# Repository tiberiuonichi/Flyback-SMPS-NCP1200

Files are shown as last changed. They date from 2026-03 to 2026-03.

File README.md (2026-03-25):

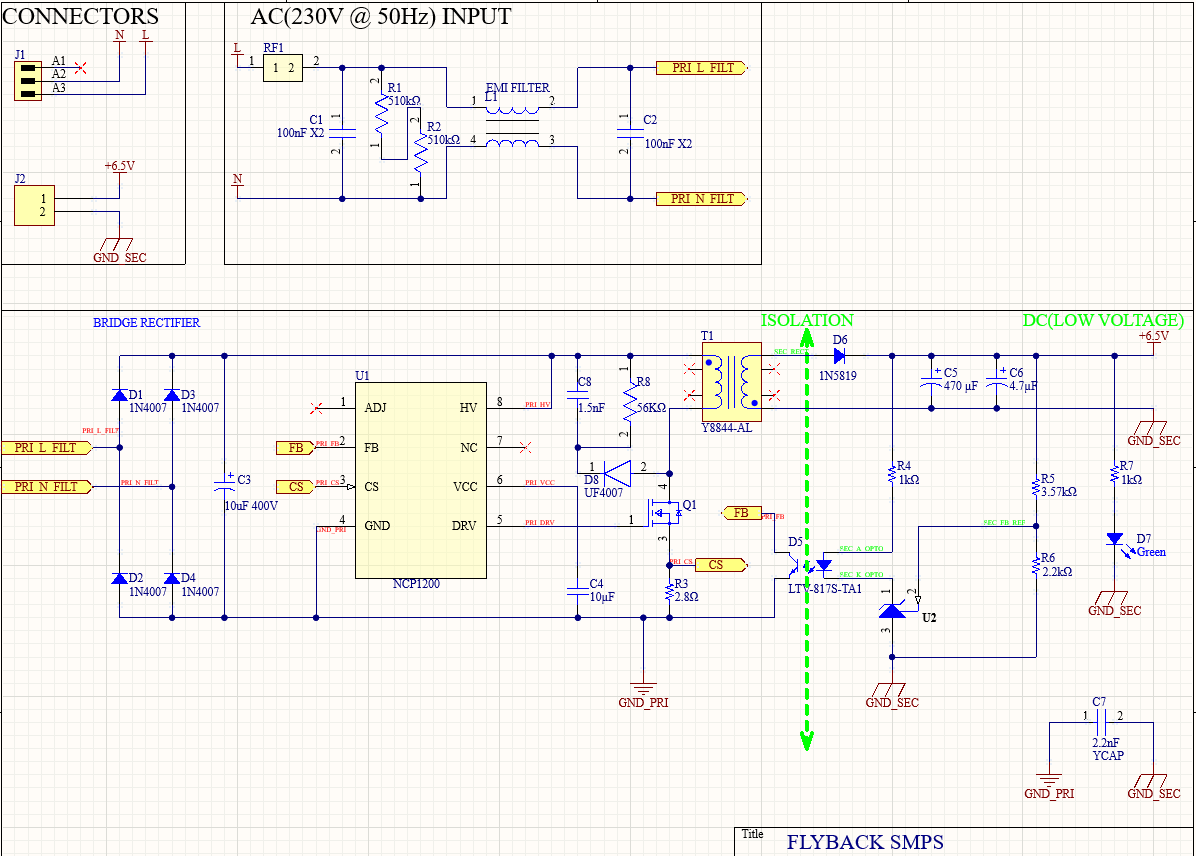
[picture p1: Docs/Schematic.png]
Schematic Preview

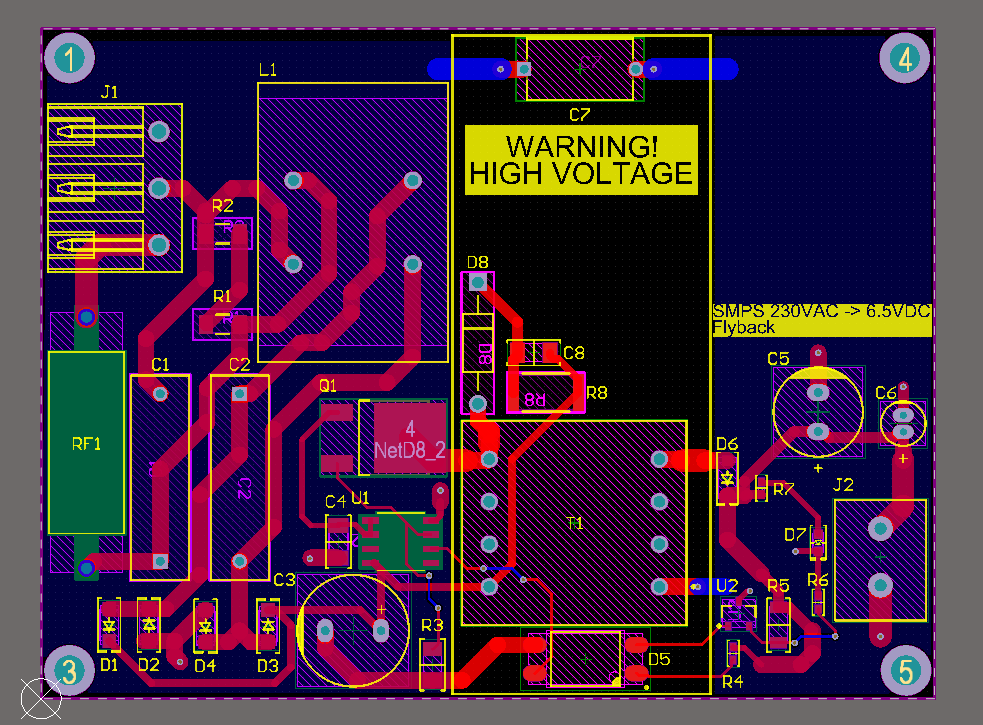
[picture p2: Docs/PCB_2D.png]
2D PCB Preview

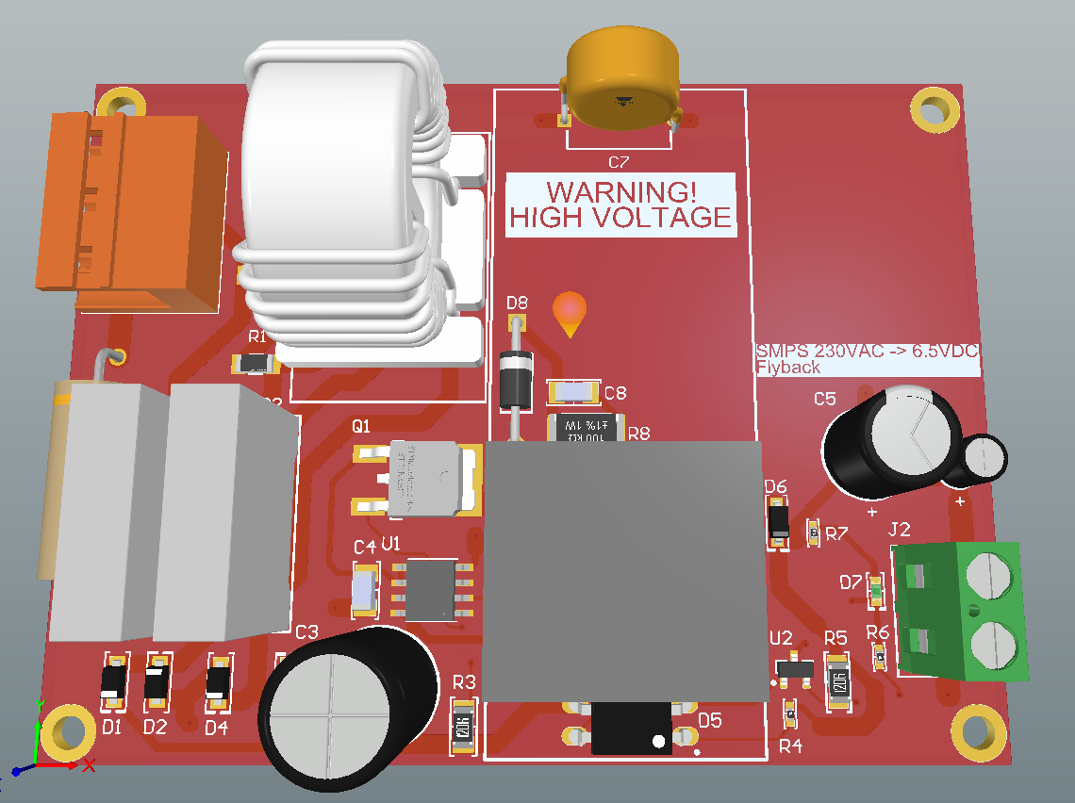
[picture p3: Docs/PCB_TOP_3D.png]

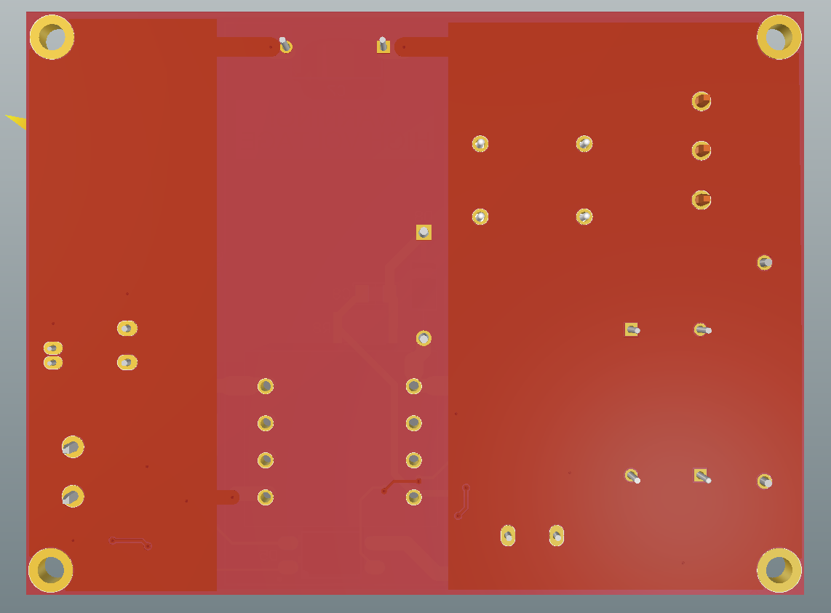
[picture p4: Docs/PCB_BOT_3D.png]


# 15W Isolated Flyback SMPS (230VAC to 6.5VDC)

## Project Overview
This repository contains the full hardware design for a compact, high-voltage Switch Mode Power Supply (SMPS). The design is based on the NCP1200 PWM controller and is optimized for low component count while maintaining high reliability and safety.

The project was developed using Altium Designer and includes everything from schematics and PCB layout to manufacturing files (Gerbers) and a detailed Bill of Materials (BOM).

## Technical Specifications
| Parameter | Value |
|---|---|
| Input Voltage | 230V AC @ 50Hz (Nominal) |
| Output Voltage | 6.5V DC (Regulated) |
| Max Power Output | ~15W |
| Topology | Isolated Flyback |
| Controller | ON Semi NCP1200 (Current-Mode PWM) |
| Switching Freq | 100 kHz |
| Feedback Loop | Optoisolated (LTV-817) with TL431 Shunt Regulator |

## Key Features and Design Decisions

### 1. Safety and Mechanical Design (Class I Isolation)
The input connector (J1) features a 3-pin configuration where Pin 3 is designated for Protective Earth (PE).
- Chassis Grounding: The design is intended to be housed in a metallic enclosure where PE is bonded to the chassis.
- Creepage and Clearance: PCB layout follows strict distance rules between Primary and Secondary sides to ensure galvanic isolation and user safety.

### 2. EMI Management
To comply with electromagnetic compatibility standards, the design includes:
- Input Pi-Filter: Common Mode Choke (L1) and X2 Capacitor (C1,C2) to reduce conducted emissions.
- Y-Capacitors (C7): Strategically placed to provide a low-impedance path for switching noise across the isolation barrier.

### 3. Efficiency and BOM Optimization
- NCP1200 Benefits: By using the NCP1200's internal high-voltage current source for startup, the design eliminates the need for an auxiliary transformer winding, significantly reducing transformer complexity and cost.

## Project Structure
- /Design_Files: Altium Designer source files (.PrjPcb, .SchDoc, .PcbDoc, and Libraries).
- /Manufacturing: Production-ready files (Gerber Files, NC Drill, and BOM).
- /Docs: Full project documentation, including schematics and 3D renders.

## Safety Warning
HIGH VOLTAGE HAZARD: This circuit operates at 230V AC. Lethal voltages are present on the primary side. This project is for educational and professional evaluation purposes only. Use an isolation transformer and follow all safety protocols when testing.

- **Full Project Documentation:** [Download Flyback_SMPS.pdf](Docs/Flyback_SMPS.pdf)

---
- **Designed by:** Onichi Ionut-Tiberiu  
- **Tools:** Altium Designer, GitHub Desktop.

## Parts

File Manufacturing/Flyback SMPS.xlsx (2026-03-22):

Line # | Name | Description | Designator | Revision ID | Revision State | Revision Status | Quantity | Manufacturer 1 | Manufacturer Part Number 1 | Manufacturer Lifecycle 1 | Supplier 1 | Supplier Part Number 1 | Supplier Unit Price 1 | Supplier Subtotal 1
 | 100nF X2 | CAP FILM 0.1UF 10% 560VDC RADIAL | C1, C2 |  | Unknown server |  | 2
 | 10uF 400V | CAP 10 UF 20% 400 V | C3 |  | Not managed |  | 1 | Wurth Elektronik | 860241375002 |  | DigiKey | 732-9301-1-ND | 0.88 | 0.88
 | 10µF | CAP CER 10UF 50V X5R 1206 | C4 |  | Not managed |  | 1 |  |  |  | DigiKey | 478-9979-1-ND
 | 470 µF | CAP ALUM 470UF 20% 16V RADIAL | C5 |  | Not managed |  | 1 | Nichicon | UKW1C471MPD1TD | Volume Production | DigiKey | 493-10758-1-ND | 0.7 | 0.7
 | 4.7µF | CAP ALUM 4.7UF 20% 16V RADIAL | C6 |  | Not managed |  | 1 |  |  |  | DigiKey | 493-10248-1-ND
 | YCAP | 2200 pF ±20% 500VAC Ceramic Capacitor Y5V (F) Radial, Disc | C7 |  | Unknown server |  | 1 | Vishay | VY1222M37Y5VQ63V0 | Volume Production | Arrow Electronics | VY1222M37Y5VQ63V0 | 0.1621 | 0.1621
 | 1500 pF | CAP CER 1206 1.5NF 2000V X7R 10% | C8 |  | Not managed |  | 1 |  |  |  | DigiKey | 399-16682-1-ND
 | 1N4007 | STANDARD RECTIFIER 1000V SOD-123 | D1, D2, D3, D4 |  | Not managed |  | 4 | Sangdest Microelectronics | 1N4007FL | Volume Production | DigiKey | 1655-1N4007FLCT-ND | 0.13 | 0.52
 | LTV-817S-TA1 | OPTOISOLATR 5KV TRANSISTOR 4-SMD | D5 |  | Not managed |  | 1 | Lite-On | LTV-817S-TA1 | Volume Production | DigiKey | 160-1893-1-ND | 0.32 | 0.32
 | 1N5819 | DIODE SCHOTTKY 40V 1A SOD123 | D6 |  | Not managed |  | 1 | Diodes Inc. | 1N5819HW-7-F | Volume Production | DigiKey | 1N5819HW-FDICT-ND
 | Green | NEXT GENERATION OF CHIP LED 0603 | D7 |  | Not managed |  | 1 | Osram Opto | LT Q99G.01-R2T1-25-1-5-R18 |  | DigiKey | 475-LTQ99G.01-R2T1-25-1CT-ND | 0.15 | 0.15
 | UF4007 | DIODE GEN PURP 1KV 1A DO41 | D8 |  | Unknown server |  | 1
 | 1146740000 | OMNIMATE Signal - series BL/SL 5.08 | J1 |  | Unknown server |  | 1
 | 282837-2 | TERM BLK 2P SIDE ENT 5.08MM PCB | J2 |  | Not managed |  | 1 | TE Connectivity | 282837-2 | Volume Production | DigiKey | A113320-ND | 0.87 | 0.87
 | 744823305 | THT Common Mode Power Line Choke WE-CMB, L = 5.00 mH | L1 |  | Not managed |  | 1
 | STD1NK60T4 | N-Channel 600V 1A (Tc) 30W (Tc) Surface Mount DPAK | Q1 |  | Unknown server |  | 1 | STMicroelectronics | STD1NK60T4 | Volume Production | Mouser | 511-STD1NK60 | 1.38 | 1.38
 | 510kΩ | Thick Film Chip Resistors 1206 510kΩ 0.25W 5% 200ppm/°C | R1, R2 |  | Unknown server |  | 2
 | 2.8Ω | CPF 1206 2R8 0.1% 25PPM 1K RL | R3 |  | Not managed |  | 1 |  |  |  | DigiKey | 1712-CPF1206B2R8E1CT-ND
 | 1kΩ | RES SMD 1K OHM 0.1% 1/16W 0402 | R4, R7 |  | Not managed |  | 2 |  |  |  | DigiKey | A119928CT-ND
 | 220 Ohms | RES 3.57K OHM 1% 1/16W 0402 | R5 |  | Not managed |  | 1 |  |  |  | DigiKey | YAG3150CT-ND
 | 2.2kΩ | RES SMD 2.2K OHM 0.5% 1/16W 0402 | R6 |  | Not managed |  | 1 |  |  |  | DigiKey | RR05P2.2KDCT-ND
 | 56KΩ | CRGCQ2512 56KΩ 1W ±100ppm/°C 1%200V | R8 |  | Unknown server |  | 1
 | FW30A10R0JA | Description | RF1 |  | Not managed |  | 1
 | Y8844-AL | Flyback Transformer, 3.5 W, -40 to 85 degC, 18.3 x 20.1 x 14 mm Package | T1 |  | Not managed |  | 1
 | NCP1200 | No Description Available | U1 |  | Not managed |  | 1
 | TL431AQDBZRQ1 | Automotive Catalog Adjustable Precision Shunt Regulator, 34 ppm / degC, 100 mA, -40 to 125 degC, 3-pin SOT-23 (DBZ), Green (RoHS & no Sb/Br) | U2 |  | Not managed |  | 1

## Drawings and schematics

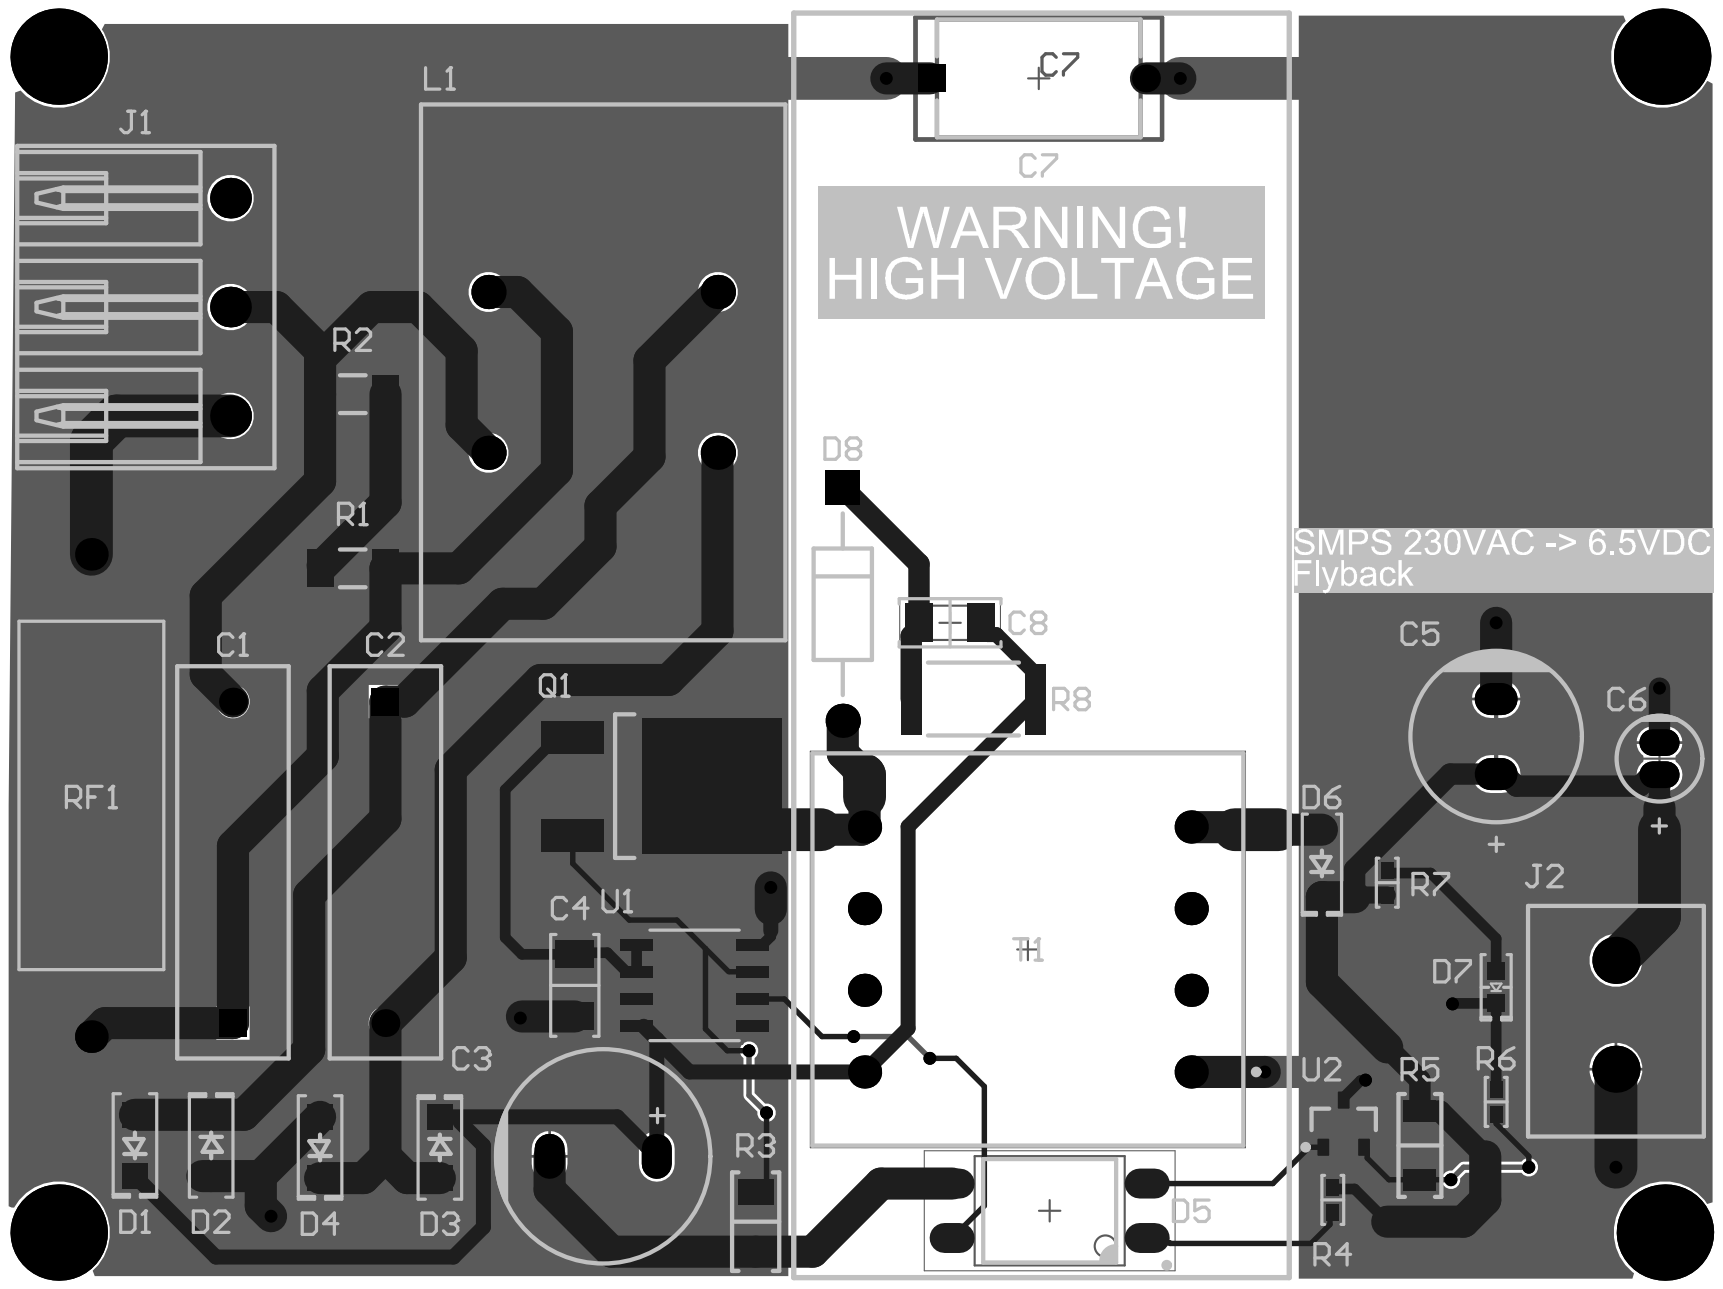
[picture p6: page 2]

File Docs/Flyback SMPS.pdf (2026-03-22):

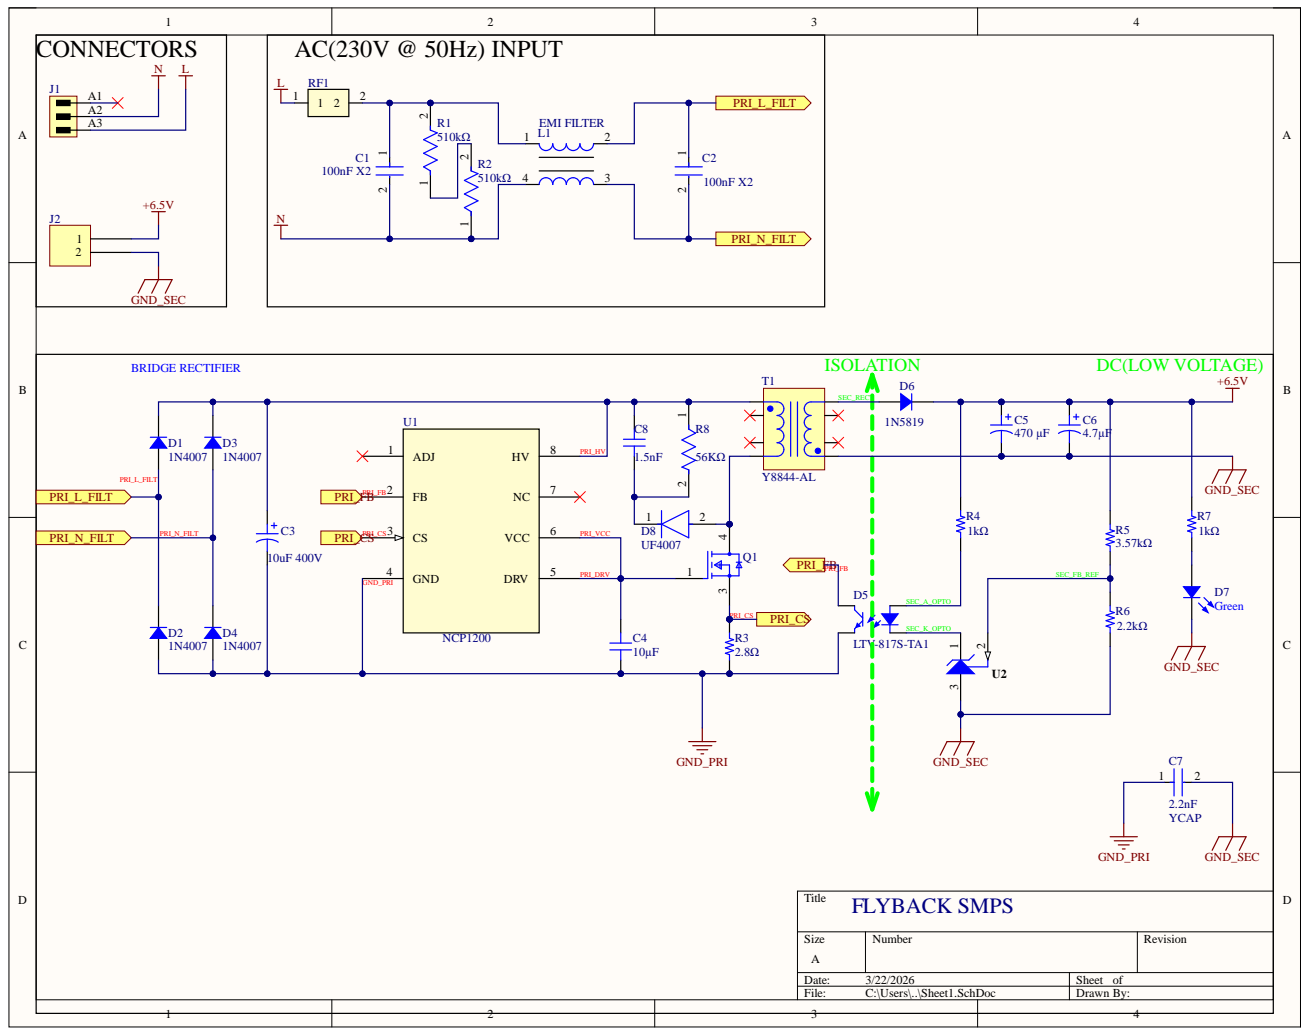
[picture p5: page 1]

Size A | Number | Revision

Date: 3/22/2026 | Sheet of
